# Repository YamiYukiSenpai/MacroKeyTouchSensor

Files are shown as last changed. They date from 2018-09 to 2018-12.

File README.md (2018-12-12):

# MacroKeyTouchSensor

## Table of Contents
* [Parts](#parts)
* [Time Commitment](#time)
* [Connecting the MPR121 to Raspberry Pi with the breadboard](#breadboard_connect)
* [PCB & Soldering](#pcb_solder)
* [Assembly](#assembly)
* [Power Up](#powerup)
* [Unit Testing](#unit_testng)

## <a name="parts">Parts</a>
* Raspberry Pi + microSD card
* Copper tape
* A platform
    *  Can be cardboard, acrylic casing (like mine)
*  Wire strippers
*  Breadboard cables
*  Breadboard

Note: expect to pay roughly $150 in parts

## <a name="time">Time Commitment</a>
The hardware portion of the project can be done in about a week, if you follow the instructions directly & spent at least 2 hours per day on this project.  Maybe 3 weeks to 2 months if you make modificatons.  The Gantt chart below shows how much time I allocated assuming I work once to twice a week

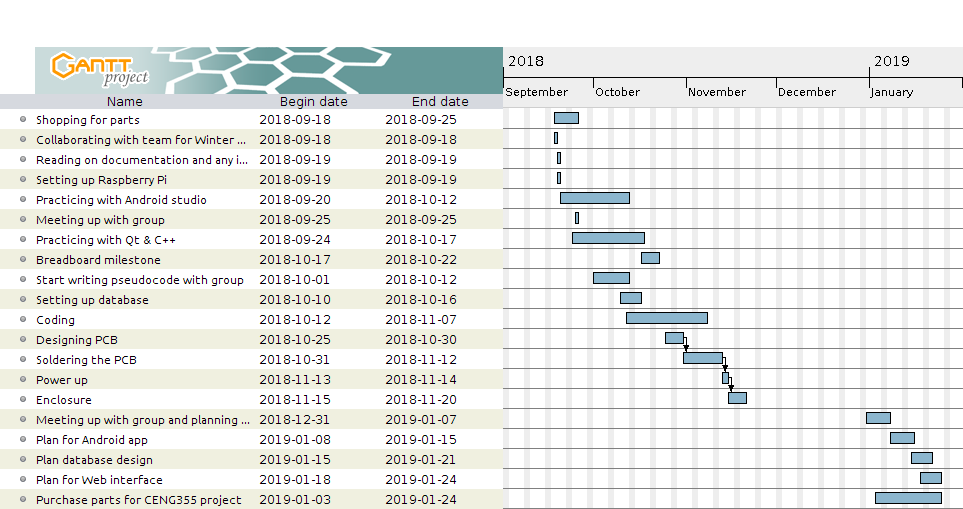
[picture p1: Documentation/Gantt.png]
Gantt


##  Connecting the MPR121 breakout sensor to the Raspberry Pi with the breadboard

See [this part of the guide](#breakout_solder) for soldering the breakout board before testing.

### Testing on the breadboard
Connecting to the breadboard is crucial because we don't want our hard work to go to waste if the sensor turns out to be a paperweight.

1. Connect the following pins on the MPR121 breakout board to the Raspberry Pi
    *  MPR121 Vin - Pi 3.3V
    *  MPR121 GND - Pi GND
    *  MPR121 SCL - Pi SCL
    *  MPR121 SDA - Pi SDA

2. Make sure that the Pi can detect any I2C input.
    * `sudo raspi-config` on the terminal
    * Select "Interfacing"
    * Select "I2C" then select "yes" when it asks you if you want to enable it.
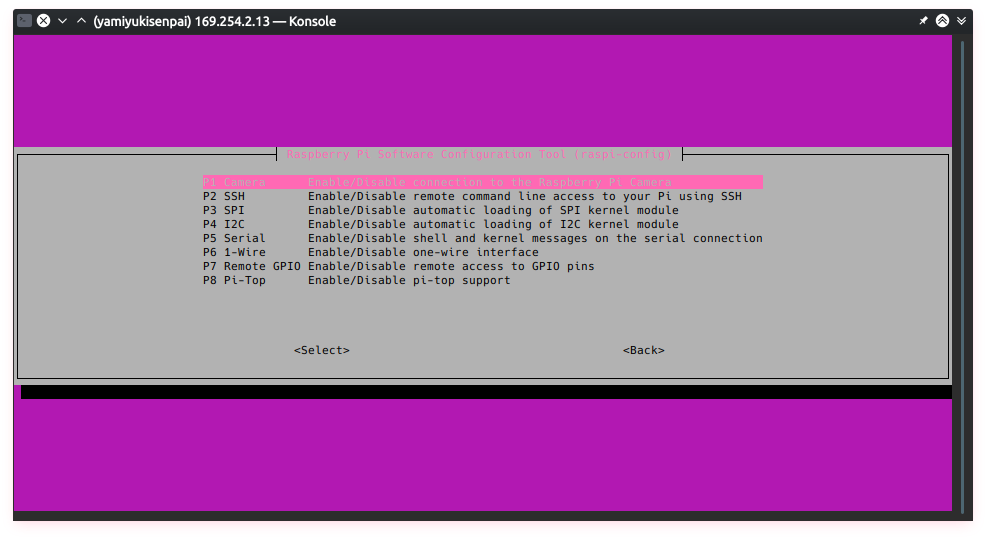
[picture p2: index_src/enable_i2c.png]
enable I2C
    
3. Test out if the sensor works with `sudo i2c-detect -y 1` on the Pi's terminal.

## <a name="pcb_solder">PCB & Soldering</a>

Soldering the MPR121 breakout requires 2 separate headers, 1 for each side.

### Printing the PCB
The gerber files required for the printing of the PCB are in `Schematics/MacroKeyTouchSensor_gerber`.  Modify the Fritzing file in the Schematics directory, and export to gerber if modfifications are needed.

### <a name="breakout_solder">Soldering the pins to the breakout board</a>
Make sure that the side you're soldering is the short side.  In addition, make sure that no pins interfere with others.  This is one of the harder ones as there are a lot of them and they're tightly packed together.

### Soldering to the PCB
When you start soldering the PCB, make sure to solder one of the headers underneath the PCB for it to connect to the Raspberry Pi.

The rest of the headers gets soldered at the top side of the PCB.

*Hint: Best to go for less pins connected to the Pi itself because it can get really hard to take out if you're not careful.*

 

### Optional: Solder a wire and a breadboard wire together
Cut a normal wire and a breadboard wire in half.  Make sure that the overall length is approximately 13cm.  Solder the 2 wires together. Afterwards, strip the other end for conection to the case.  Make 12 of these.

This is optional because a normal wire can be plugged in, but a breadboard wire is more secure.

## <a name="assembly">Assembly</a>
A basic case with 12 pre-made holes for the sensor's 12 points are in the Schematics directory under the file name `MacroKeyTouchSensor_case.cdr`.  Make sure that the you have CorelDraw to make the case, but it can be converted to a standard `.svg` file.

1. Insert the stripped end of the wire to the holes on top of the case.  Cover it up with copper tape for wider touch target.
2. Once all 12 pins are secured on the case, connect the other end each of their respective pins.
3. Attach each side of the case to each other.

## <a name="powerup">Power up</a>
* Power up the Pi, and run `sudo i2cdetect -y 1`
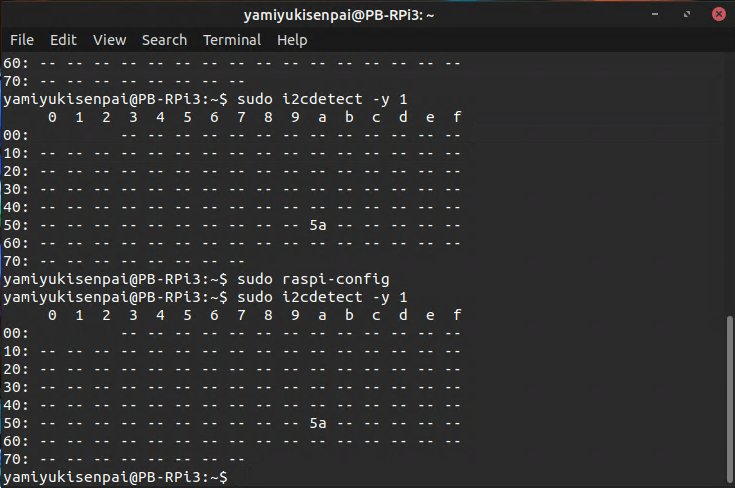
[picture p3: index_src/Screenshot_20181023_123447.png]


## <a name="unit_testing">Unit Testing</a>
* The repo also comes with a Python 2 test code under the file name `cap-touch.py`.  Place the file on your the root of the home directory of your Pi (not in Documents, Downloads, etc.), and run the command `python cap-touch.py`.  Touch each of the nodes on your case to make sure it responds.

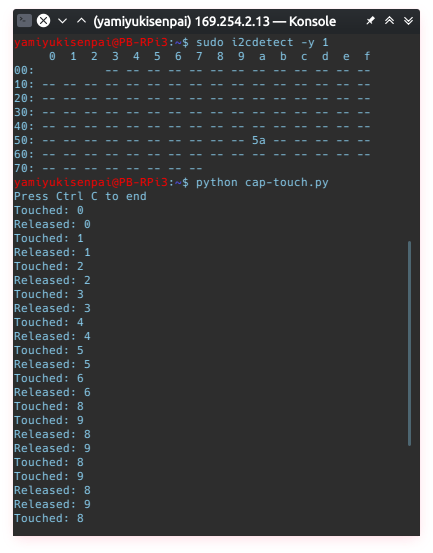
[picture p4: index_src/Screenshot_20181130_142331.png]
test run


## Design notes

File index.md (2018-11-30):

MacroKeyTouchSensor
===============

Week 13 Modified Case Design & Presentation prep
------------
### New case design
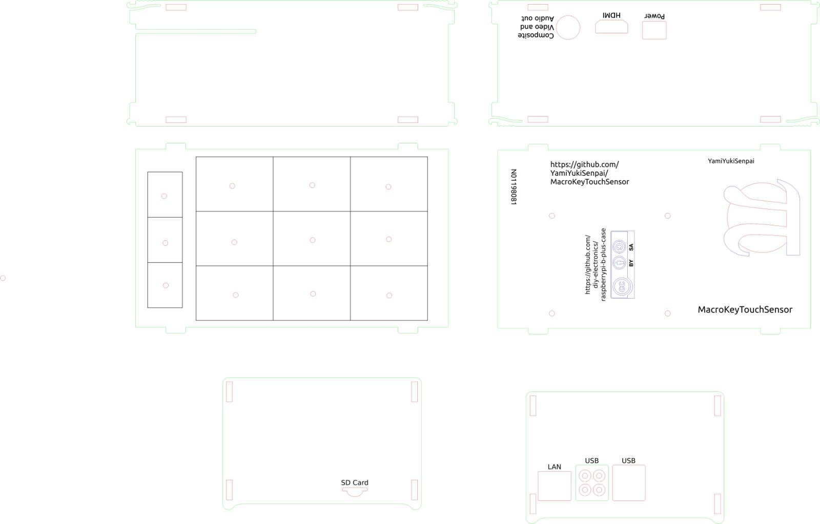
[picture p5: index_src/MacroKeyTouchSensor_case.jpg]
new case

The case that I designed last week didn't fit properly because the slots are misaligned.  Even breaking the pieces didn't help.  Over the weekend, I had a stroke of inspiration when I saw my calculator which led to the case's current design.
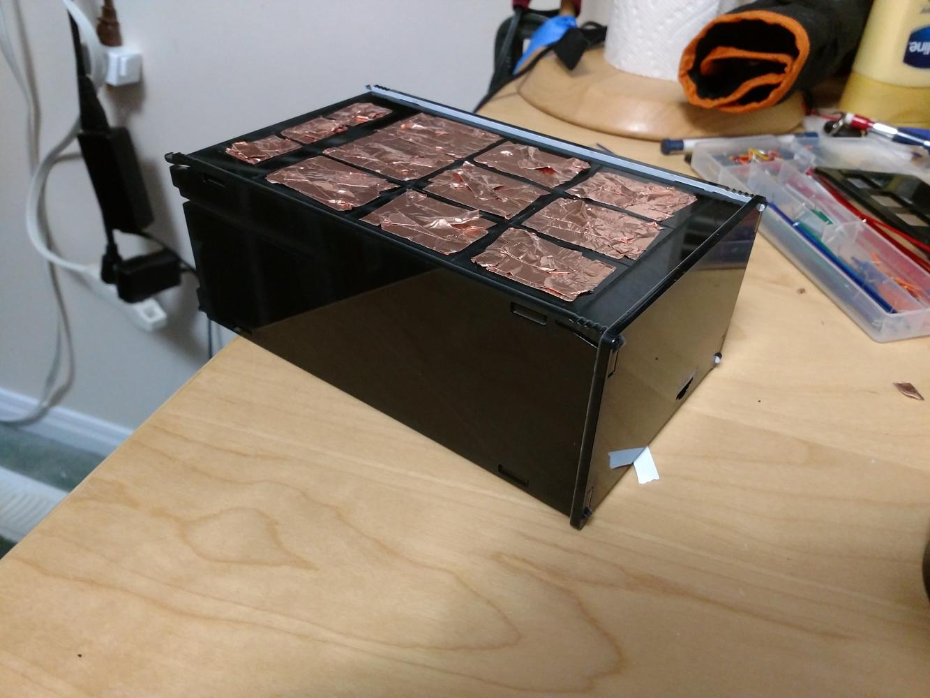
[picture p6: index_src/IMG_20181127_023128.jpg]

Yes, I'm aware this is very late, but it took me 4 tries to get it right.  And unfortunately, the ethernet and USB ports aren't aligned properly.  I had to elevate the Raspberry Pi 3 because the power supply would not get in the hole.  However, I think, as of right now, the device will function fine without that part of the case.

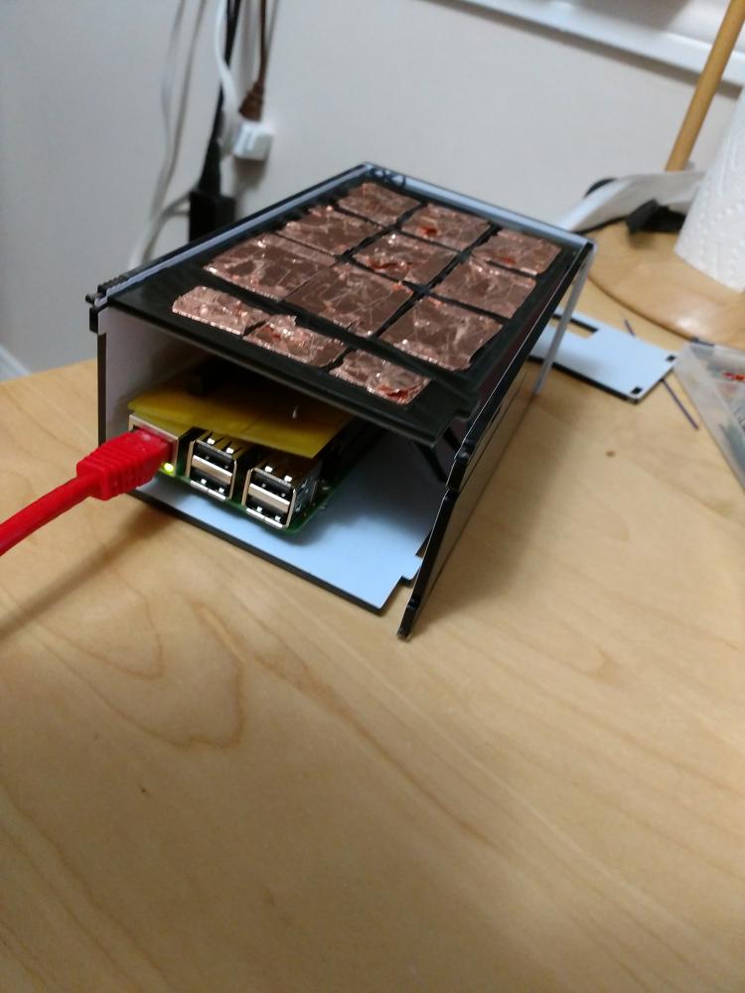
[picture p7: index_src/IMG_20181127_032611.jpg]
no back


## Presentation preparation
I started creating the [presention](MacroKeyTouchSensor_presentation.odp) that's going to be presented on December 4, 2018.

Week 12 Case design
------
### Activities vs Schedule
I am currently behind on the project.  I still need the case to be made.  I did finish the schematics today on CorelDRAW and sent it to the prototype lab.
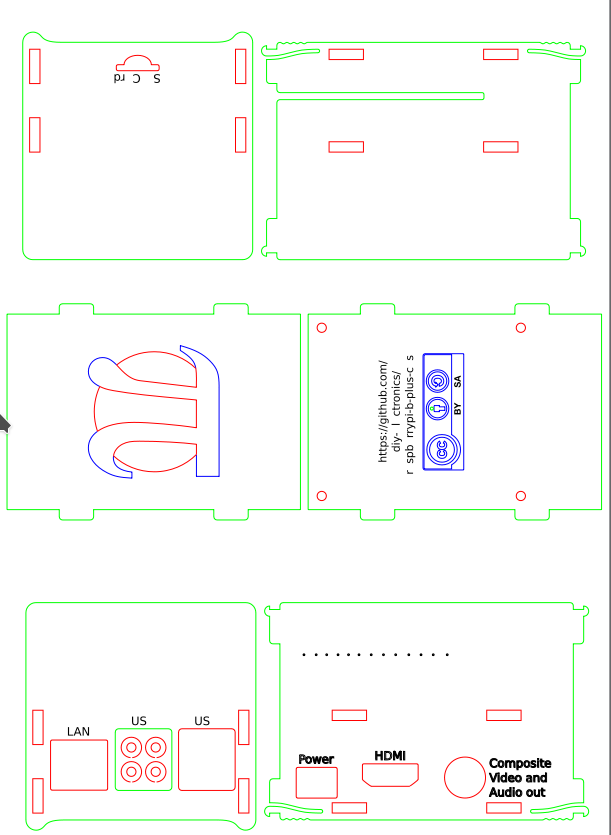
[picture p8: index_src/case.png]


### Problems
I had a smaller PCB made.  The headers got stuck on the Pi, and I had to resolder it becuase it removed some of the pins from the headers that are attached to the Pi.

Week 11 Testing the sensor
------------------------
### Actvities vs Schedule
I am currently on track with the project.  I had the project tested with a python code [I found on the internet](https://www.mbtechworks.com/projects/mpr121-capacitive-touch-for-raspberry-pi-project.html), which works.  The goal now is to make a case that will work with the PCB.

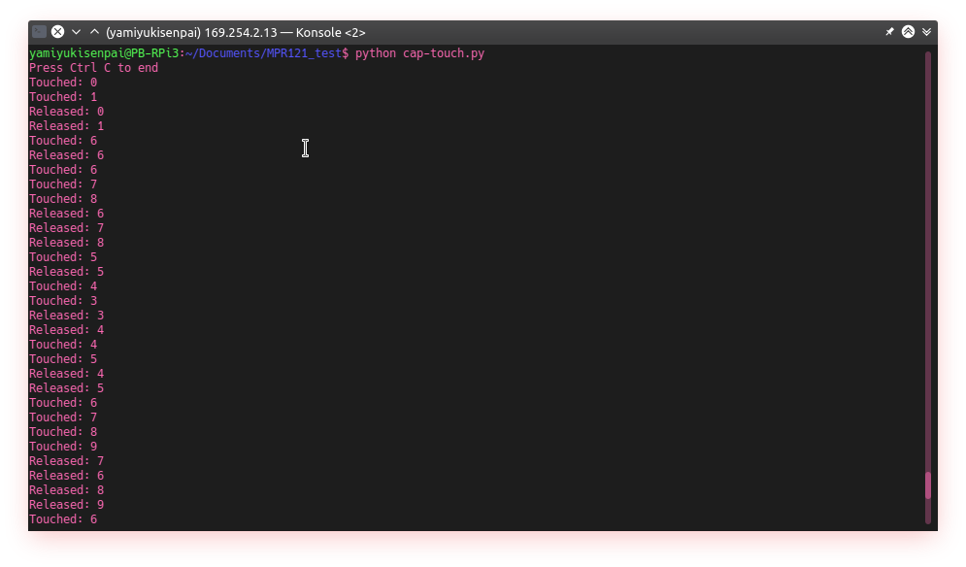
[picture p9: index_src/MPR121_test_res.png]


Week 10 Soldering Milestone
-----------------

### Actvities vs Schedule
I am currently behind schedule and cannot complete the soldering milestone today.  I did more research on code for it, [especially in C](https://github.com/sparkfun/MPR121_Capacitive_Touch_Breakout/blob/master/Firmware/MPR121Q/C%20code/main.c).

### Problem
The PCB's header hole are wider than it should've been.  I decided to delete the sensor and just manually create the headers for it.  The PCB is expected to be ready by tomorrow, November 7.

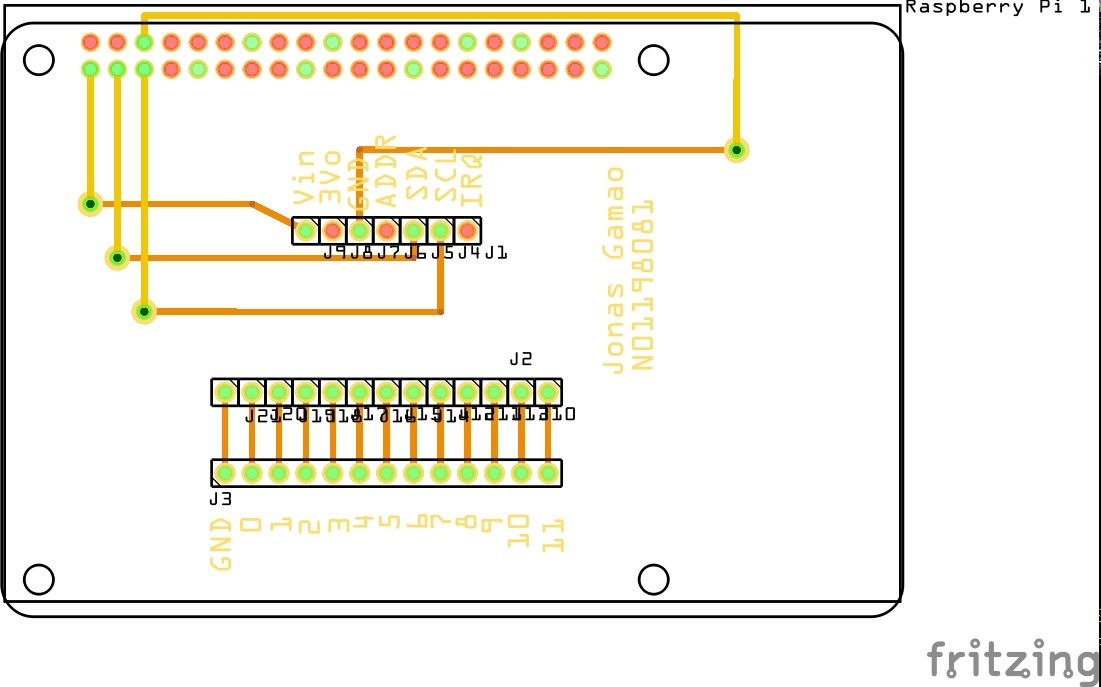
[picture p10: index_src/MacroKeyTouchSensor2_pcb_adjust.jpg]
PCB readjusted


### Financial status
No other purchases necessary for this week.

###

Week 9 Fritzing and PCB
--------------

### Activities vs Schedule
I am currently slightly behind on the project due to the sensor not being correct on Fritzing's database

### Problem
The main problem is that Fritzing doesn't have the correect sensor in their database MPR121 does exist but it's missing 2 pins.  The one in their GitHub page is also outdated.

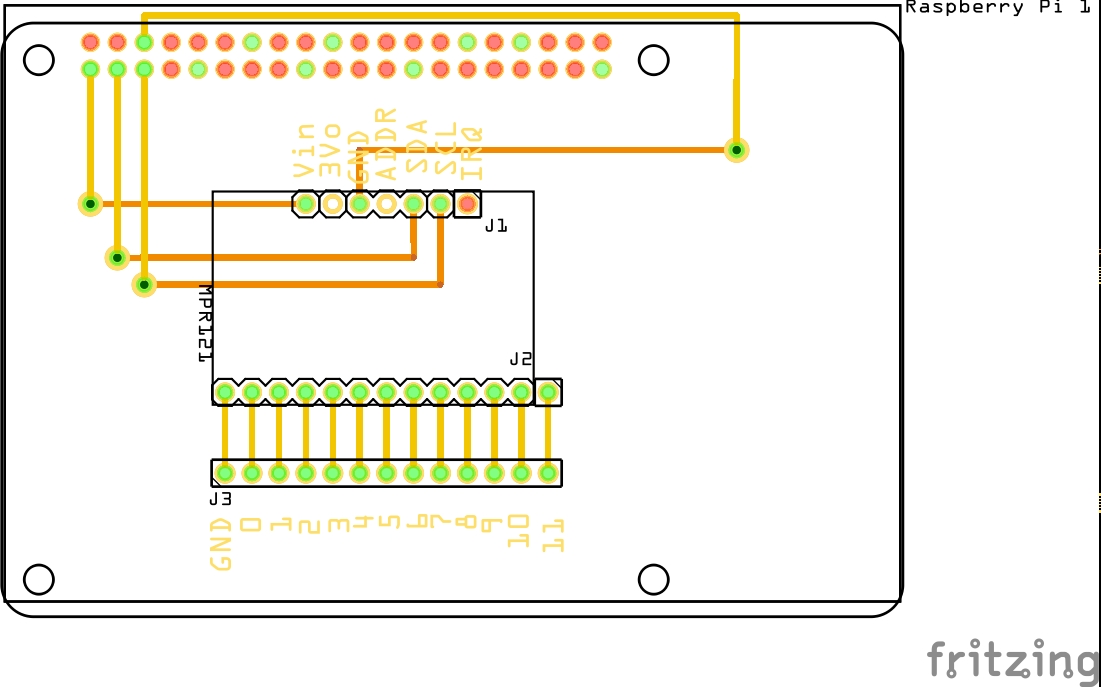
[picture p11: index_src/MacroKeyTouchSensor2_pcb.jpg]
PCB


Week 8 Basic Breadboard assembly
---------------
### Activities vs the Schedule
As of right now, I'm on schedule with the project.  The component seems to be soldered correct and the Raspberry Pi 3 detected the device.
i2cdetect

### Problems
The only problem I experienced today was that I made mistakes with the soldering, where I bridged some of my pins by accident.  This caused me to finish the soldering a lot longer than expected.  Last week, my MPR121 sensor had not arrived, and fell slightly behind with the soldering component.

### Financial Status
The first sensor was bought without paying for express shipping, but I did not expect the shipping dates to have a very wide margin.  Therefore, I ended up buying another sensor and paid for express shipping for it.  It ended up being a waste of money because both of them arrived on Friday, October 19.

MPR121 with breadboard
MPR121 with breadboard

Week 5 Proof of purchase
-------------
### Items delivered before this week
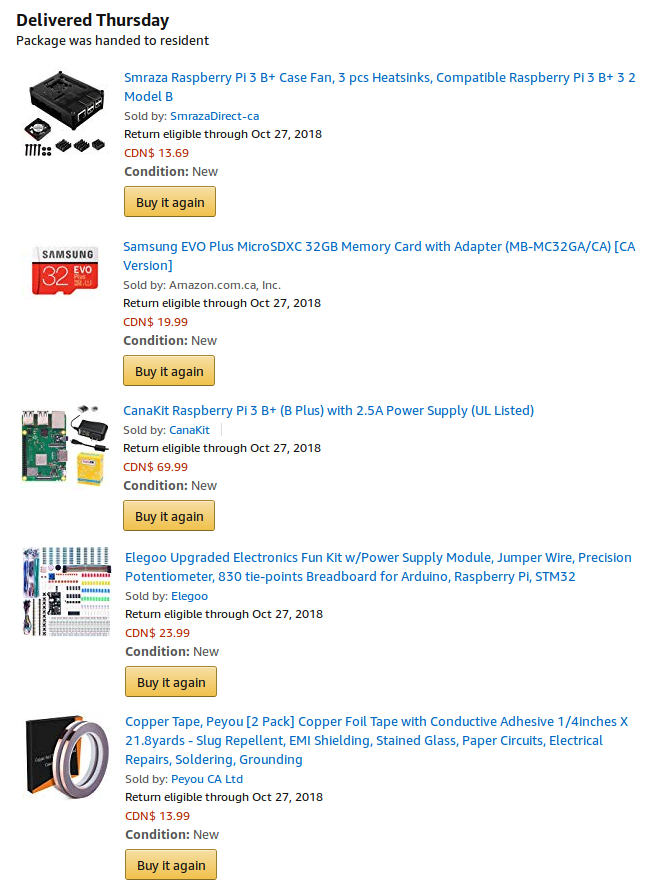
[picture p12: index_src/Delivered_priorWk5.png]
Items delivered before this week


### Items pending delivery
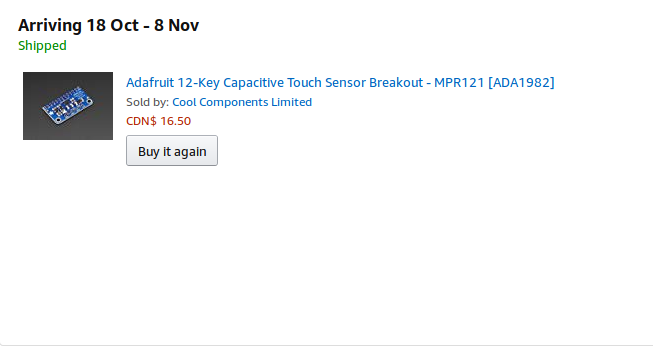
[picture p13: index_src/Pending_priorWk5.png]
Items still on its way


Week 4
---------------

Created [budget document](Documentation/JonasGamao_N01198081_budget.xlsx)

Week 3
----------------

Created [Gantt chart](Documentation/Gantt.gan)

Week 2
---------------

Created [Proposal Content](Documentation/ProposalContentJonasGamao.xlsx)

Created the GitHub repository

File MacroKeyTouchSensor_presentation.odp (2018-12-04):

## MacroKeyTouchSensor

Jonas Gamao

## Introduction

- A device that uses the MPR121 capacitive touch sensor as a “macro keyboard”
- Uses the copper tape as conductive material to widen the touch target

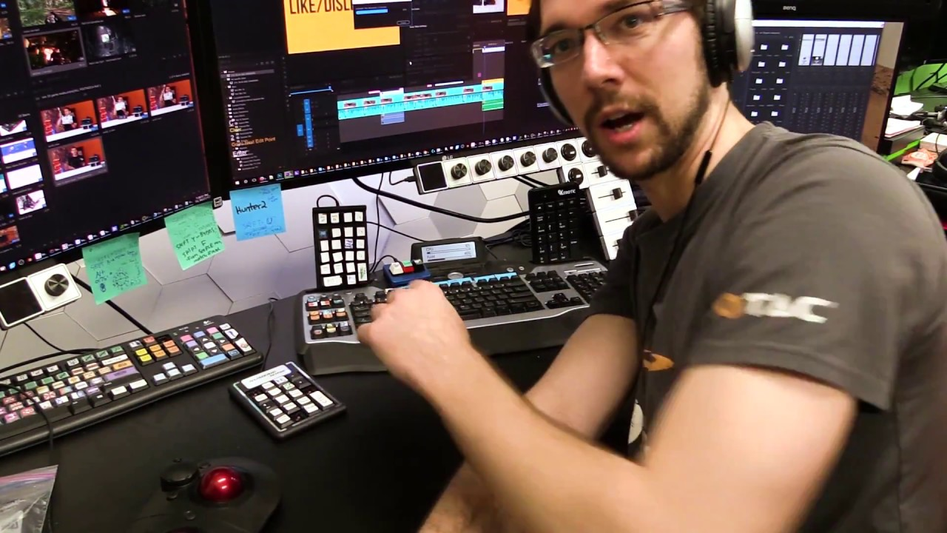
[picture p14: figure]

## Testing


- Used a basic test code found on MBTechWorks (https://www.mbtechworks.com/projects/mpr121-capacitive-touch-for-raspberry-pi-project.html)

## Budget

- Spent $149.46 on parts
  - Bought everything this semester other than the parts kit
  - MPR121 12-Key Capacitive Touch Sensor breakout
  - Raspberry Pi 3 Model B
  - 32GB MicroSD card
  - Copper tape
  - Elegoo Electronics Kit
  - Comes with a breadboard, M-F & M-M breadboard cables, etc.

## Schedule


## Knowledge from Previous Courses

- TECH 101 – Electronic Circuits
- WRIT 120 – Technical Reading and Writing
- CENG 200 – Unix Scripting
- TECH

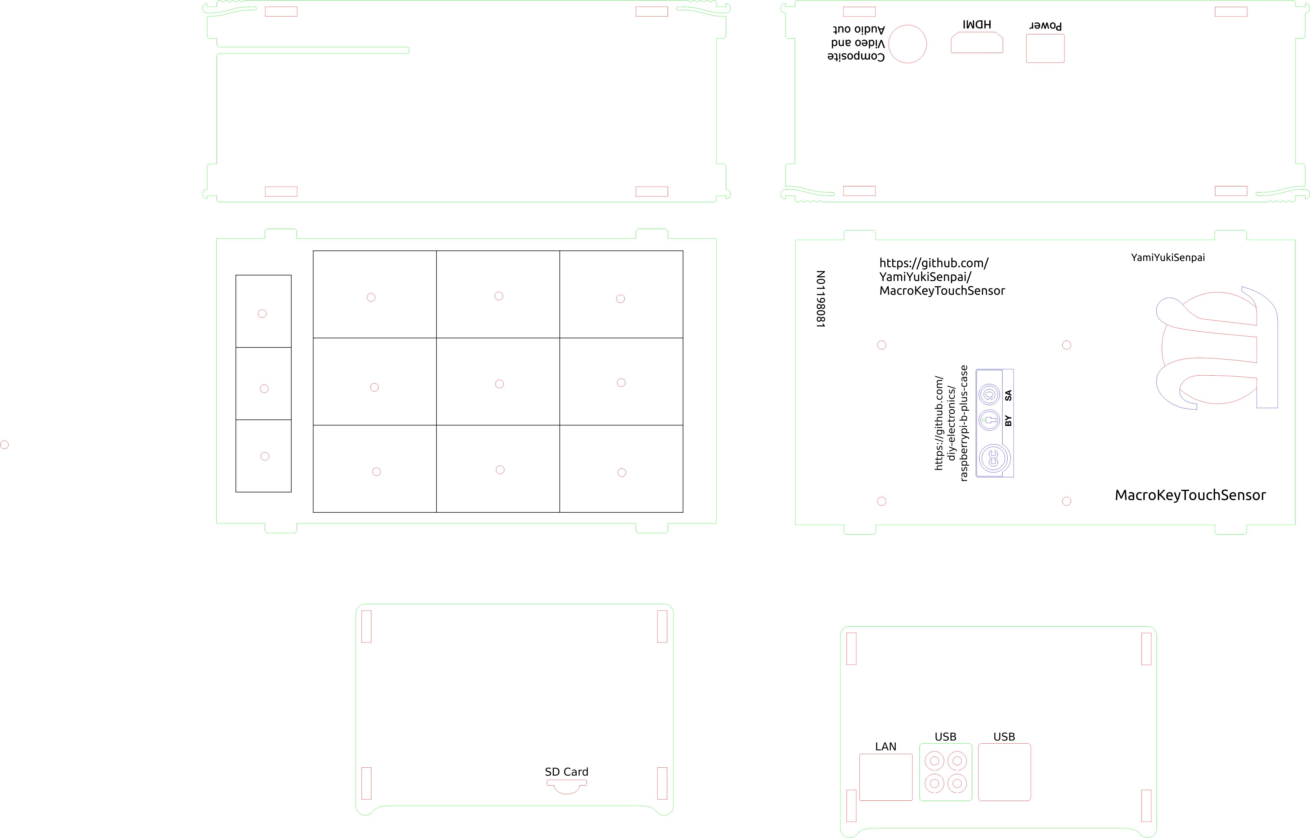
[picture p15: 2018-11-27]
index_src/MacroKeyTouchSensor_case (2).jpg

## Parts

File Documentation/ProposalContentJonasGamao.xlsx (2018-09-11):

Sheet: DataEntry
Submission Date | 2018-09-11
Project Name | Macro Keyboard Touch Sensor (name might change)
Student Name | Jonas Gamao
Project repository | https://github.com/YamiYukiSenpai/MacroKeyTouchSensor
SensorEffector choice | MPR121 12-point capacitive touch sensor (0x5D)
The database will store | Input data from the touch sensor, predefined and custom macros
The mobile device functionality will include | Launching software, or doing certain actions with a touch of a button (similar to Blackberry’s speed key)
I will be collaborating with the following company/department | School of Applied Technology
My group in the winter semester will include | Ryan Maynard, Delory Chrisite
50 word problem statement | Programming the hardware to interact with the software, creating multiple macros, having the option to create custom macros, controlling another hardware with the sensor from a distance, and storing predetermined and custom macros in the database.
100 words of background | The capacitive sensor is what capacitive touch screen are based on. The technology can detect any conductive or dielectric material, like our human body. This allowed capacitive touch screen to be operated without the need to apply significant amount of pressure in order to operate. However, not every object can interact with it because the capacitive sensor requires a conductive material (i.e. specialized gloves with conductive tips) in order for it to respond to input. This makes a standard stylus useless to interact with a capacitive touch screen.
Current product APA citation | Wulff, A. (2017, September 24). Capacitive Touch Keyboard Extension with Leonardo. Retrieved from https://www.hackster.io/AlexWulff/capacitive-touch-keyboard-extension-with-leonardo-13a387
Existing research IEEE paper APA citation | Ruan, J., Chao, P. C., & Chen, W. (2010). A multi-touch interface circuit for a large-sized capacitive touch panel. 2010 IEEE Sensors. doi:10.1109/icsens.2010.5689881
Brief description of planned purchases | Currently planning on purchasing the MPR121 sensor from Adafruit, PCB, copper tape
Solution description | For user-friendly touch sensor to assist with navigation and better usability

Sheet: DataBase
Submission Date | Project Name | Student Name | Project repository | SensorEffector choice | The database will store | The mobile device functionality will include | I will be collaborating with the following company/department | My group in the winter semester will include | 50 word problem statement | 100 words of background | Current product APA citation | Existing research IEEE paper APA citation | Brief description of planned purchases | Solution description
43354 | Macro Keyboard Touch Sensor (name might change) | Jonas Gamao | https://github.com/YamiYukiSenpai/MacroKeyTouchSensor | MPR121 12-point capacitive touch sensor (0x5D) | Input data from the touch sensor, predefined and custom macros | Launching software, or doing certain actions with a touch of a button (similar to Blackberry’s speed key) | School of Applied Technology | Ryan Maynard, Delory Chrisite | Programming the hardware to interact with the software, creating multiple macros, having the option to create custom macros, controlling another hardware with the sensor from a distance, and storing predetermined and custom macros in the database. | The capacitive sensor is what capacitive touch screen are based on. The technology can detect any conductive or dielectric material, like our human body. This allowed capacitive touch screen to be operated without the need to apply significant amount of pressure in order to operate. However, not every object can interact with it because the capacitive sensor requires a conductive material (i.e. specialized gloves with conductive tips) in order for it to respond to input. This makes a standard stylus useless to interact with a capacitive touch screen. | Wulff, A. (2017, September 24). Capacitive Touch Keyboard Extension with Leonardo. Retrieved from https://www.hackster.io/AlexWulff/capacitive-touch-keyboard-extension-with-leonardo-13a387 | Ruan, J., Chao, P. C., & Chen, W. (2010). A multi-touch interface circuit for a large-sized capacitive touch panel. 2010 IEEE Sensors. doi:10.1109/icsens.2010.5689881 | Currently planning on purchasing the MPR121 sensor from Adafruit, PCB, copper tape | For user-friendly touch sensor to assist with navigation and better usability

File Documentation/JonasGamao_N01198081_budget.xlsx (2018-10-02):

Jonas Gamao
Hardware Production Budget
Part # | Description | Quantity | Supplier | Cost (1) | Shipping | Subtotal
Need to buy
ADA1982 | MPR121 12-key capacitive touch sensor | 1 | Amazon | $16.50 | 0 | $16.50
PE115-0054-11-CA | Peyou [2 Pack] Copper Foil Tape with Conductive Adhesive 1/4inches X 21.8yard | 1 | Amazon | $13.99 | 0 | $13.99
EL-CK-003 | Elegoo Upgraded Electronics Fun Kit | 1 | Amazon | $23.99 | 0 | $23.99
MB-MC32GA/CA | 32GB Samsung EVO Plus microSDXC | 1 | Amazon | $24.99 | 0 | $24.99
99218 | CanaKit Raspberry Pi 3 B+ (B Plus) with 2.5A Power Supply | 1 | Amazon | $69.99 | 0 | $69.99
Currently Owned
 | Humber College Parts kit | 1 | Humber College Book store | $110.00 | 0 | $110.00
Total cost |  |  |  |  |  | $259.46
New purchase |  |  |  |  |  | $149.46
Total cost of new items with taxes |  |  |  |  |  | $149.46

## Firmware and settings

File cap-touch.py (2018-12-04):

# Based on Arduino example by Jim Lindblom
# http://bildr.org/2011/05/mpr121_arduino/
# And Scott Garner's conversion to Python
# https://github.com/scottgarner/BeetBox
# And helpful examples from Adafruit

# Found on https://www.mbtechworks.com/projects/mpr121-capacitive-touch-for-raspberry-pi-project.html

import pygame
import time, threading
import RPi.GPIO as GPIO
import smbus
bus = smbus.SMBus(1) # Pi 2

# MPR121 Register Defines
MHD_R = 0x2B
NHD_R = 0x2C
NCL_R = 0x2D
FDL_R = 0x2E
MHD_F = 0x2F
NHD_F = 0x30
NCL_F = 0x31
FDL_F = 0x32
ELE0_T = 0x41
ELE0_R = 0x42
ELE1_T = 0x43
ELE1_R = 0x44
ELE2_T = 0x45
ELE2_R = 0x46
ELE3_T = 0x47
ELE3_R = 0x48
ELE4_T = 0x49
ELE4_R = 0x4A
ELE5_T = 0x4B
ELE5_R = 0x4C
ELE6_T = 0x4D
ELE6_R = 0x4E
ELE7_T = 0x4F
ELE7_R = 0x50
ELE8_T = 0x51
ELE8_R = 0x52
ELE9_T = 0x53
ELE9_R = 0x54
ELE10_T = 0x55
ELE10_R = 0x56
ELE11_T = 0x57
ELE11_R = 0x58
FIL_CFG = 0x5D
ELE_CFG = 0x5E
GPIO_CTRL0 = 0x73
GPIO_CTRL1 = 0x74
GPIO_DATA = 0x75
GPIO_DIR = 0x76
GPIO_EN = 0x77
GPIO_SET = 0x78
GPIO_CLEAR = 0x79
GPIO_TOGGLE = 0x7A
ATO_CFG0 = 0x7B
ATO_CFGU = 0x7D
ATO_CFGL = 0x7E
ATO_CFGT = 0x7F

# Global Constants

TOU_THRESH = 06
REL_THRESH = 12

# Routines

def readData(address):
#	MSB = bus.read_byte_data(address, 0x00)
#	LSB = bus.read_byte_data(address, 0x01)
	touchData = bus.read_word_data(address, 0x01)
	return touchData

def setup(address):

	bus.write_byte_data(address, ELE_CFG, 0x00)

	# Section A - Controls filtering when data is > baseline.
	 
	bus.write_byte_data(address, MHD_R, 0x01)
	bus.write_byte_data(address, NHD_R, 0x01)
	bus.write_byte_data(address, NCL_R, 0x00)
	bus.write_byte_data(address, FDL_R, 0x00)

	# Section B - Controls filtering when data is < baseline.

	bus.write_byte_data(address, MHD_F, 0x01)
	bus.write_byte_data(address, NHD_F, 0x01)
	bus.write_byte_data(address, NCL_F, 0xFF)
	bus.write_byte_data(address, FDL_F, 0x02)	

	#Section C - Sets touch and release thresholds for each electrode

	bus.write_byte_data(address, ELE0_T, TOU_THRESH)
	bus.write_byte_data(address, ELE0_R, REL_THRESH)

	bus.write_byte_data(address, ELE1_T, TOU_THRESH)
	bus.write_byte_data(address, ELE1_R, REL_THRESH)

	bus.write_byte_data(address, ELE2_T, TOU_THRESH)
	bus.write_byte_data(address, ELE2_R, REL_THRESH)

	bus.write_byte_data(address, ELE3_T, TOU_THRESH)
	bus.write_byte_data(address, ELE3_R, REL_THRESH)

	bus.write_byte_data(address, ELE4_T, TOU_THRESH)
	bus.write_byte_data(address, ELE4_R, REL_THRESH)

	bus.write_byte_data(address, ELE5_T, TOU_THRESH)
	bus.write_byte_data(address, ELE5_R, REL_THRESH)

	bus.write_byte_data(address, ELE6_T, TOU_THRESH)
	bus.write_byte_data(address, ELE6_R, REL_THRESH)

	bus.write_byte_data(address, ELE7_T, TOU_THRESH)
	bus.write_byte_data(address, ELE7_R, REL_THRESH)

	bus.write_byte_data(address, ELE8_T, TOU_THRESH)
	bus.write_byte_data(address, ELE8_R, REL_THRESH)

	bus.write_byte_data(address, ELE9_T, TOU_THRESH)
	bus.write_byte_data(address, ELE9_R, REL_THRESH)

	bus.write_byte_data(address, ELE10_T, TOU_THRESH)
	bus.write_byte_data(address, ELE10_R, REL_THRESH)

	bus.write_byte_data(address, ELE11_T, TOU_THRESH)
	bus.write_byte_data(address, ELE11_R, REL_THRESH)	

	# Section D
	# Set the Filter Configuration
	# Set ESI2

	bus.write_byte_data(address, FIL_CFG, 0x04)

	# Section E
	# Electrode Configuration
	# Set ELE_CFG to 0x00 to return to standby mode

	bus.write_byte_data(address, ELE_CFG, 0x0C)  # Enables all 12 Electrodes	

#---- main -----#
TOU_THRESH = 10
REL_THRESH = 20
setup(0x5a)
last_touched = readData(0x5a)

# Use pygame for sounds
pygame.mixer.pre_init(44100, -16, 12, 512)
pygame.init()
pygame.mixer.music.set_volume(1.0)

soundsList = [
  '/opt/sonic-pi/etc/samples/drum_tom_hi_hard.wav',
  '/opt/sonic-pi/etc/samples/sn_dolf.wav',
  '/opt/sonic-pi/etc/samples/drum_tom_mid_hard.wav',
  '/opt/sonic-pi/etc/samples/drum_snare_hard.wav',
  '/opt/sonic-pi/etc/samples/drum_cymbal_open.wav',
  '/opt/sonic-pi/etc/samples/bass_voxy_c.wav',
  '/opt/sonic-pi/etc/samples/elec_bong.wav',
  '/opt/sonic-pi/etc/samples/bass_voxy_hit_c.wav',
  '/opt/sonic-pi/etc/samples/ambi_choir.wav',
  '/opt/sonic-pi/etc/samples/drum_cymbal_hard.wav',
  '/opt/sonic-pi/etc/samples/drum_splash_hard.wav',
  '/opt/sonic-pi/etc/samples/loop_amen_full.wav'
]

sounds = [0,0,0,0,0,0,0,0,0,0,0,0]
key = 0
for  sound in soundsList:
  sounds[key] = pygame.mixer.Sound(sound)
  sounds[key].set_volume(1)
  key += 1

print "Press Ctrl C to end"

lastTap = 0

while True:
  currentTap = readData(0x5a)
  for i in range(12):
    pin_bit = 1 << i
    if currentTap & pin_bit and not lastTap & pin_bit:
      print "Touched: " + str(i)
      t = threading.Thread(target=playSound, args=(i,))
      t.start()      
    if not currentTap & pin_bit and lastTap & pin_bit:
      print "Released: " + str(i)
  lastTap = currentTap
  time.sleep(0.1)

  def playSound(i):
    if (sounds[i]):
      sounds[i].play()


       

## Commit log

2018-09-11 Added ProposalContent database file
    [ProposalContentJonasGamao.xlsx]
2018-09-18 Moved the ProposalContent*.xlsx to the Documentation Folder
    [ProposalContentJonasGamao.xlsx]
2018-10-02 Added budget file
    [JonasGamao_N01198081_budget.xlsx]
2018-10-30 Project Fritzing schematics
    [MacroKeyTouchSensor.fzz, MacroKeyTouchSensor2.fzz]
2018-10-31 Added Gerber files
    [MacroKeyTouchSensor2.fzz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]
2018-10-31 Updated PCB file
2018-11-06 Adjusted the PCB for both sides to be closer together
    [MacroKeyTouchSensor2.fzz, Schematics.kicad_pcb, Schematics.sch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]
2018-11-20 added case schematics
2018-11-22 Adjusted the case schematics
2018-11-25 Updated case
2018-11-27 Update for device case
2018-12-04 Moved relevant files to gerber folder
    [MacroKeyTouchSensor2_contour.gm1, MacroKeyTouchSensor2_copperBottom.gbl, MacroKeyTouchSensor2_copperTop.gtl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]
2018-12-04 Removed irrelevant files
    [MacroKeyTouchSensor.fzz, Schematics.kicad_pcb, Schematics.sch]
